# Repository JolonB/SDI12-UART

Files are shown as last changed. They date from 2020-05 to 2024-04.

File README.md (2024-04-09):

# SDI12-UART

Microcontroller independent implementation of SDI-12 over UART.
May also work for any sort of single wire communications protocol (not tested).

- [What is this?](#what-is-this)
- [What is SDI-12?](#what-is-sdi-12)
- [SDI-12 Protocol](#sdi-12-protocol)
  - [Electrical Interface](#electrical-interface)
  - [Communication](#communication)
- [Implementation](#implementation)
- [Glossary](#glossary)
- [References](#references)

---

## What is this?

After working on a project involving the use of SDI-12 sensors, I realised there was no SDI-12 library that was suitable for *any* microcontroller (well, any microcontroller that supports UART).
I was aware of the [Arduino-SDI-12](https://github.com/EnviroDIY/Arduino-SDI-12) library which was implemented entirely in software, but that uses the Arduino core library so would not work on *any* microcontroller.
(If you're working with Arduino, the Arduino-SDI-12 library may be the best if you're ok with the restrictions of the SoftwareSerial library).

The goal of this repository is to show a simple way to implement SDI-12 on *any* device with a UART driver.
"How?", you might ask.
Easy!
With hardware.

If you already know about SDI-12, feel free to skip to [Implementation](#implementation).

## What is SDI-12?

The SDI-12 (serial digial interface at 1200 baud) protocol was first released in 1988 designed by the US Geological Surbey's Hydrologic Instrumentation Facility and some private companies.
The SDI-12 specification is maintained by the SDI-12 Support group [1].

SDI-12 is a protocol often used for environmental monitoring due to it's low power operation.
It is intended for use in systems that are battery powered, low cost, and require a multiple sensors attached to one cable.
The SDI-12 protocol supports at least 10 sensors each with a cable length of 60 metres (200 feet).
One key reason for using SDI-12 sensors is that *all* SDI-12 sensors follow the protocol in the exact same way (barring slight differences between versions), so a variety of sensors can be used with little to no changes to the system [2].

## SDI-12 Protocol

*All information from [2]*.

### Electrical Interface

The SDI-12 protocol uses 2-3 wires to power and communicate with the sensor.
The figure below shows the bus connections.

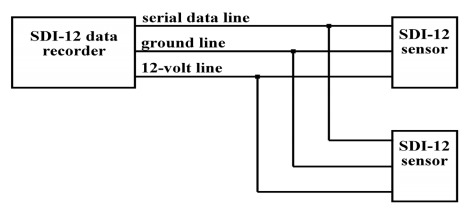
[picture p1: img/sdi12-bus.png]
SDI-12 bus


It is possible to not connect the 12 V line on some sensors, however, that is outside the scope of this repository.

The serial data line is a bidirectional (half-duplex) data transfer line.
It uses inverted logic as shown in the table below.

| Condition | Binary State | Voltage Range |
| --- | --- | --- |
| marking | 1 | -0.5-1.0 V |
| spacing | 0 | 3.5-5.5 V |
| transition | undefined | 1.0-3.5 V |

The 12 V line must be supplied with between 9.6 V and 16 V.

### Communication

#### Data

The SDI-12 protocol specifies that data recorders and sensors communicate via the exchange of printable ASCII characters over the data line.
"Printable ASCII characters" range from \<space\> (hex: 20) to ~ (hex: 7E).
There are three exceptions to this rule:

- responses from a sensor end with a carriage return and linefeed (`\r\n` or \<CR\>\<LF\>)
- CRC codes may include some non-printable ASCII characters
- packets returned by the High Volume Binary command

None of these use the most significant bit, which means that each "byte" of data needs to only be represented by 7 bits.
The full format for an SDI-12 byte frame is:

- 1 start bit
- 7 data bits, LSB first
- 1 even parity bit
- 1 stop bit

The first byte of any message should be the sensor address.
This is `0` by default but can be changed to any number from `0`-`9`.
Some sensors may support additional addresses from `A`-`Z` and `a`-`z`.

Rather than explaining all the commands, I will just point you to page 8 (Table 5) of [[2]](http://www.sdi-12.org/current_specification/SDI-12_version-1_4-Jan-10-2019.pdf).
Note that all commands begin with the sensor address (or `?` for wildcard) and end with `!`.
Certain manufacturers may have additional commands, but the main command set should be unchanged.

#### Timing

The image below shows a timing diagram for the SDI-12 protocol.
The tolerance for all timing is &pm;0.40 ms.
The only exception is the time between the stop bit of one character and the start bit of the next which should not be more than 1.66 ms.

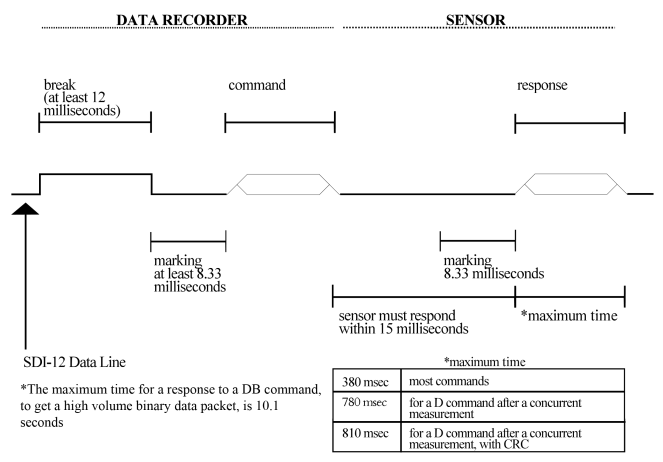
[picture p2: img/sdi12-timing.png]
SDI-12 timing


It should be noted that this diagram shows the **voltage levels** and not the **binary states**.
As in, a break is a period of spacing, which is a high voltage, but a low binary state.

The full communication protocol (for the data recorder) is explained below:

- data recorder sends a break by setting the data line to spacing (5 V) for at least 12 ms.
The sensor will never recognise a break less than 6.5 ms and will always recognise one greater than 12 ms.
- data recorder sends marking (0 V) for 8.33 ms.
This cannot be any longer than 100 ms otherwise sensors will go to sleep.
- data recorder sends the command to the sensor.
- data recorder gives up control of the data line within 7.5 ms of the end of the last stop bit and waits to receive data.

This must be repeated for every command if the sensors have fallen asleep again.
This occurs if a different sensor is addressed or if 87 ms of marking was detected by the sensor.

#### Retries (not yet implemented)

A data recorder must support retries.
A retry is needed if there was:

- no response from the sensor at least 16.67 ms after the last stop bit of the command.
- 8.33 ms of marking on the data line, after receiving the start bit of the response
- an invalid response

The first retry can be issued between 16.67 ms and 87 ms from the end of the last stop bit of the command.
If no valid response is received after retrying at least two times (with one retry more than 100 ms after the end of the break), the entire sequence of break and retries should be repeated two more times.

## Implementation

The implementation of SDI-12 was based heavily on the work done in [3].
The work I did can be found [here](https://jolonb.github.io/assets/pdf/final_report.pdf) if you're interested.
The goal is to make this information a bit more widely available and to provide alternate approaches for different microcontrollers.

There are so many types of microcontrollers so it's impossible to provide one solution for all of them.
This repository will showcase a few different ways to make it work.
Feel free to submit a pull request if you can add another design or make any changes to something.  
In any case, the base design will work for any microcontroller as the hardware works with standard UART.
Different designs can be created for specific use cases.

The most basic implementation is shown below.

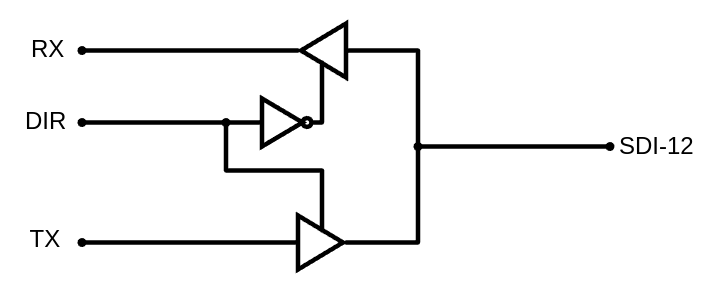
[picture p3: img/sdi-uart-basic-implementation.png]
Simplest SDI-UART implementation


This consists of two tri-state buffers and one inverter.
There may also need to be a high-value pull-down resistor (100–300kΩ) on the SDI-12 line, however, I'm not sure if that is built in to the sensor (if someone knows, let me know!)  
_However_, this implementation is unlikely to work in most situations for three reasons:

- It does not invert the logic. This only works if the microcontroller UART hardware supports inverted logic, or if the tri-state buffers are actually tri-state inverters (see [logic inversion](#logic-inversion)).
- It is assumed that this circuit operates at 5V because the SDI-12 specification requires 5V logic. If you are using a 3.3V microcontroller, you will need logic level shifters (see [logic levels](#logic-levels)).
- The TX line must be capable of sending a 12ms break signal. This can be done with hardware or sometimes in software (see [12-ms break](#12-ms-break)).

There are two modes of operation: transmit and receive.
The specifics of how it works will depend on the hardware you purchase; this information explains the operation of the circuit in the image above.  
When the DIR pin is set HIGH, the transmitter buffer is activated.
The signal on the Tx line will be propogated through to the SDI-12 line.
It will also go to the receive buffer, however, the inverter disables the receive buffer so nothing is read.
Technically, the RX tri-state buffer and inverter is optional if you choose to ignore any data received while transmitting, much like in [this circuit](https://archive.is/j75iI).
If the RX tri-state buffer _is_ included, it can then be enabled by setting the DIR pin LOW and allowing data received from the SDI-12 sensor to be received.

<!-- At the moment, there are 4 properties of the microcontroller you need to be aware of: inverted, reinitialisable, default voltage, and high voltage level.
Refer to the [glossary](#glossary) for definitions of these terms.

| Configuration | | Inverted | Reinitialisable | Default Voltage | High Voltage [V] |
| --- | --- | --- | --- | --- | --- |
| [1](hardware/config_1) | | No | No | LOW | 3.3 | -->

### Logic Inversion

TODO
<!-- TODO -->

### Logic Levels

TODO
<!-- TODO - maybe mention work in hardware/README.md -->

### 12-ms Break

If your microcontroller doesn't support sending a break signal of at least 12 ms, you will need to implement it another way.
There are two ways this can be done: with hardware, or with software.

The software approach is cheaper, but is not supported by all microcontrollers.
To do this, you need to close the serial device, set the output on the Tx line for 12 ms, and re-enable the serial device.
The following Arduino code shows how this could be done:

```c++
void sendSDI12Break() {
  Serial.flush();  // make sure everything has been sent
  Serial.end();  // disable serial
  pinMode(txPin, OUTPUT);  // set Tx pin to output
  digitalWrite(txPin, HIGH);  // or LOW if inverting signal with hardware
  delay(12);  // break for minimum of 12ms
  Serial.begin(1200, 7E1);  // re-enable serial
}
```

Remember, this isn't guaranteed to work on all microcontrollers.
I suggest testing this code (or similar code) before selecting the hardware.

The hardware approach is guaranteed to work for all devices, provided they have one free GPIO pin.
This involves connecting the Tx signal to the new GPIO through either an AND or OR gate (depending on whether you've inverted the logic in the microcontroller or on the PCB).
You can see this implemented below.
In this circuit, it is assumed that the microcontroller is inverting the logic, so an OR gate is used.
This allows the break signal to be sent by setting the FOut ("**F**orce **Out**") pin HIGH for 12 ms.

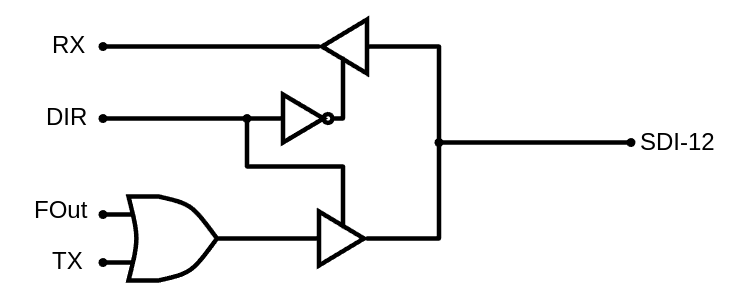
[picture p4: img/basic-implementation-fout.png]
SDI-UART implementation


While the FOut pin is LOW (default state), the output will be the same as the Tx pin.
The truth table for this is shown below.

| FOut | Tx | OUT |
| --- | --- | --- |
| 0 | 0 | 0 |
| 0 | 1 | 1 |
| 1 | X | 1 |

If you were inverting the logic in hardware, such as with tri-state buffers, you might consider using an AND gate instead and set the FOut pin LOW.
The truth table would change in this situation.

## Glossary

| Term | Meaning |
| --- | --- |
| CRC | Cyclic redundancy check, a form of error checking. |
| data recorder | The microcontroller being used to communicate with the sensor. |
| default voltage | The voltage (HIGH or LOW) on the Tx pin when not transmitting. This is almost always going to be HIGH, but it may vary for some microcontrollers. Only important if UART is not reinitialisable. |
| high voltage level | The voltage (in volts) of a HIGH signal. |
| inverted | In this context, refers to the UART driver outputting an inverted signal. This is likely the only case where default voltage is LOW. |
| reinitialisable | The ability for the UART to be initialised again after being deinitialised. |

## References

[1] Wikipedia Contributers, "SDI-12," Wikipedia, The Free Encyclopedia., 6 June 2017. [Online]. Available: [https://en.wikipedia.org/w/index.php?title=SDI-12&oldid=784017978](https://en.wikipedia.org/w/index.php?title=SDI-12&oldid=784017978). [Accessed 25 May 2020].  
[2] SDI-12 Support Group, "SDI-12 Specification," 10 January 2019. [Online]. Available: [http://www.sdi-12.org/specification.php](http://www.sdi-12.org/specification.php). [Accessed 2020 May 25].  
[3] A. Saari, S. A. Hinzey, J. R. Frigo, M. C. Proicou and L. Borges, "Using SDI-12 with ST microelectronics MCU's", Los Alamos National Lab, Los Alamos, 2015.

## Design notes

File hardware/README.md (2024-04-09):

# Hardware

The purpose of this document is to provide information about the different components used in the systems.
By breaking them down, it means the sections are modularised and can be built up to create the same functionality as required for any microcontroller.

Some sections may be a little bit theory heavy.
Working is shown in case there are mistakes so people can correct them and to provide a bit more information for those interested.
The equations provide help for minimising current in power critical situations (such as battery power, which SDI-12 sensors may be connected to).
However, if you want to skip straight to the implementation, just look at the schematic image.

## Level shifter

The most energy efficient level shifter designs I could come up with is shown below.
This assumes it is being fed into a high impedance input, such as a microcontroller or the gate of another MOSFET.
The level shifters are unidirectional as there is no need for them to be bidirectional.
The 1 M&Omega; resistors represent the load, which should be high impedance.
The 100 k&Omega; resistors can be increased to reduce the current, but increasing them too far will cause it to output the wrong voltage.

There are some instructions below for selecting the resistor for the 3.3->5 Inverted level shifter, but this information may also apply to all the other designs.
This does require extra information about the device the output is going in to, so may not be useful in most instances.

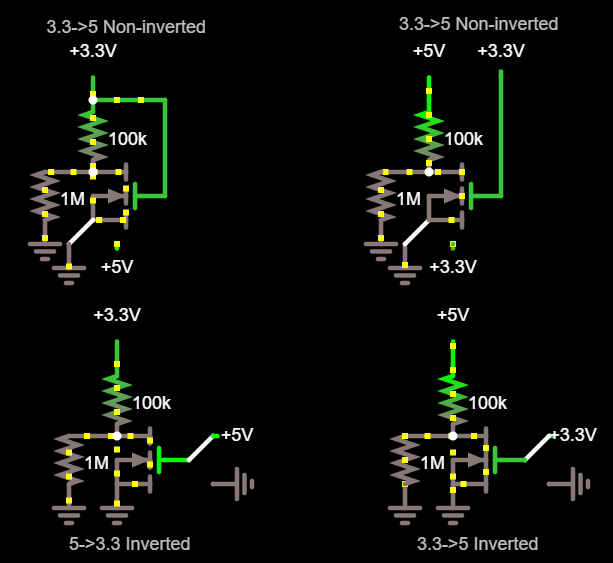
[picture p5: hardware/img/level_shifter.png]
Level shifters
  
[Link to simulation](https://www.falstad.com/circuit/circuitjs.html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)

The image below shows the output of the level shifter being fed into the input of a CMOS inverter.

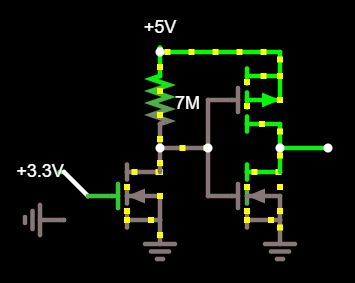
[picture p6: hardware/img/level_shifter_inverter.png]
Level shifter
  
[Link to simulation](https://www.falstad.com/circuit/circuitjs.html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)

---

If you want to work out the value of the resistor, follow these "steps" (or just skip to the end for the final equations).

When $V_{gs} = 3.3 \text{V}$, the lower left nMOS will be in the linear/non-saturation/ohmic/triode region, so the current through it is given by the equation:

$I_{ds} = \beta((V_{gs}-V_{t})V_{ds} - \frac{V_{ds}^2}{2})$

We will look at the left half of the circuit first.
We know that the current through the resistor is $I_{R} = \frac{V_{dd} - V_{ds}}{R}$ and that $I_{R} = I_{ds}$ at all times.

If we equate these and rearrange, we get:

$V_{ds}^2 - 2(\frac{1}{R\beta}+ 2V_{gs}-V_{t})V_{ds}+ 2\frac{V_{dd}}{R\beta} = 0$

We now know the input into the CMOS inverter is equal to $V_{ds}$.
Assuming the resistance is large (>1k), we know that the actual value of $V_{ds}$ is the lower solution to the quadratic.
Interestingly, the upper solution is <5V, so is technically valid but would not be the correct solution.
Therefore, we have:

$V_{ds} = \frac{1}{R\beta} + V_{gs} - V_{t} - \sqrt{(\frac{1}{R\beta} + V_{gs} - V_{t})^2 - 2\frac{V_{dd}}{R\beta}}$

Therefore, the current through the left branch is:

$I_{ds} = \frac{V_{dd} - V_{ds}}{R} = \frac{V_{dd} - \left(\frac{1}{R\beta} + V_{gs} - V_{t} - \sqrt{(\frac{1}{R\beta} + V_{gs} - V_{t})^2 - 2\frac{V_{dd}}{R\beta}}\right)}{R}$

when $V_{gs} = 3.3 \text{V}$

The calculation for when $V_{gs} = 0 \text{V}$ is a bit different in that it sets an upper bound for the resistance provided by the resistor.
You need to know the value of $I_{dss}$ for the transistor.
To simplify the explanation, this is the maximum current while the transistor is off and the value can be found on the datasheet.
Knowing this, we need to set the resistance such that $I_{R} > I_{dss}$.
Remember, $I_{dss}$ is the max current, so the current through the resistor will be limited to this value if a low enough resistance is selected.
We can write this as $\frac{V_{dd}-V_{ds}}{R} > I_{dss} \Rightarrow R < \frac{V_{dd}-V_{ds}}{I_{dss}}$.
Assuming this condition is satisfied, then $V_{ds} = V_{dd} - I_{dss}R$

In short, the current through the left branch is $I_{ds} = \frac{V_{dd} - V_{ds}}{R} = \frac{V_{dd} - \left(\frac{1}{R\beta} + V_{gs} - V_{t} - \sqrt{(\frac{1}{R\beta} + V_{gs} - V_{t})^2 - 2\frac{V_{dd}}{R\beta}}\right)}{R}$ when $V_{gs} = 3.3 \text{V}$ and $I_{ds} = I_{dss}$ when $V_{gs} = 0 \text{V}$.
$V_{ds}$ can be written as $V_{ds} = \frac{1}{R\beta} + V_{gs} - V_{t} - \sqrt{(\frac{1}{R\beta} + V_{gs} - V_{t})^2 - 2\frac{V_{dd}}{R\beta}}$ and $V_{ds} = V_{dd} - I_{dss}R$, respectively.

The next step is to feed the output of the circuit into the right branch.
This will allow you to find the optimal values to minimise the current from the source because if the output voltage is too low, the pMOS transistor will switch to the linear/saturation region. A pMOS transistor is in the off state when $V_{gs_p} > V_{t_p}$.
We know that $V_{gs_p} = V_{ds_{n1}} - V_{dd}$ and $V_{t_p}$ can be found on the datasheet.
Therefore, we have a requirement that $V_{ds_{n1}} - V_{dd} > V_{t_p}$.
The overall current of the circuit appears to be the lowest when the pMOS is on the edge of the cutoff region (it's probably best to give it a bit of breathing room though).

There's still a bit more work to do.
To get a rough idea of a resistance to use, look at [this graph](https://www.desmos.com/calculator/3hmn6u5ff4).
The resistance is on the x-axis and should not be greater than the point at which the red and purple lines intersect.
Past the intersection point, the pMOS is in linear/saturation.
The blue line represents the current (though multiplied by 100,000) through the left nMOS.
We can assume that if the pMOS is in the cutoff region that the right branch has minimal current ($I = I_{dss_p}$) therefore you only need to minimise the blue current curve.
As mentioned before, give a bit of breathing room. The default configuration in the graph would be best at 6 M&Omega;.
Make sure you play around with the values in Desmos to get the optimal value for your MOSFETs.

## Inverter

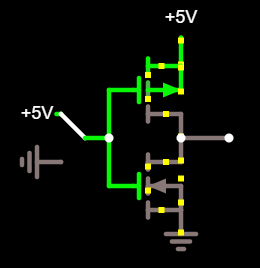
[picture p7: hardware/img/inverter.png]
Inverter
  
[Link to simulation](https://www.falstad.com/circuit/circuitjs.html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)

This is a basic CMOS inverter.
This does not have a level shifting stage because the input is already 5 V.

## Tristate Buffer

### Suggested chips

| Part number | Package |
| --- | --- |
| [SN74LV125A](http://www.ti.com/lit/ds/symlink/sn74lv125a.pdf) | TVSOP, SOIC, SOP, SSOP, TSSOP, DIP |
| [SN74LVC2G125](http://www.ti.com/lit/ds/symlink/sn74lvc2g240.pdf) | SM8, VSSOP, DSBGA |
| [SN74LVC2G241](http://www.ti.com/lit/ds/symlink/sn74lvc2g241.pdf) | SM8, VSSOP, DSBGA |

There are some differences between these buffers.
All examples will use **SN74LV125A**, so be aware of any changes you may need to make.
The other chips may be better if you don't need a DIP package as they only have two buffers rather than four.

## Basic Circuit

The following image shows a basic circuit which would work for configuration 1.
This section aims to explain how to modify this circuit to work for any other configuration.

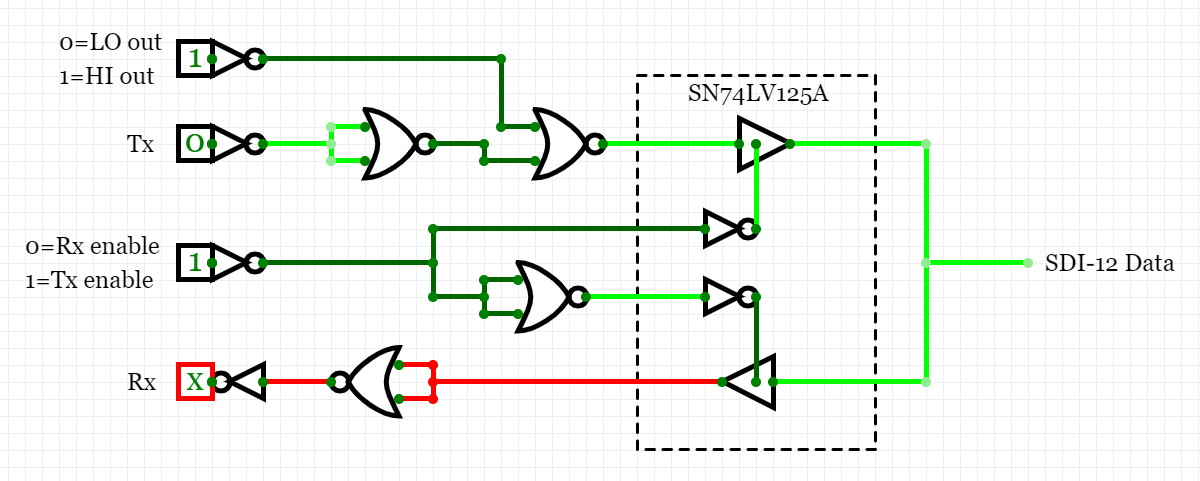
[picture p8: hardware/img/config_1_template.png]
configuration
  
[Link to "simulation"](https://circuitverse.org/users/21100/projects/95794)

Notes:

- the inverters at the inputs represent the level shifting inverters.
  - these are all inverting because inverting level shifters have a lower current draw.
- only one NOR gate is used for its intended function, the rest are used as inverters
- if the default Tx voltage is 0, place the NOR inverter *before* the NOR gate (as shown); if the default Tx voltage is 1, place the NOR inverter *after* the NOR gate.
- the inverter does not need to be on the Rx buffer enable pin (as shown), it could be connected to the Tx which would invert the control.

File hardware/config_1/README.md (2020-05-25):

# Config 1

This directory contains schematics for a device with the following properties:

- Inverted: No  
- Reinitialisable: Yes  
- Default Voltage: N/A  
- High Voltage: 3.3

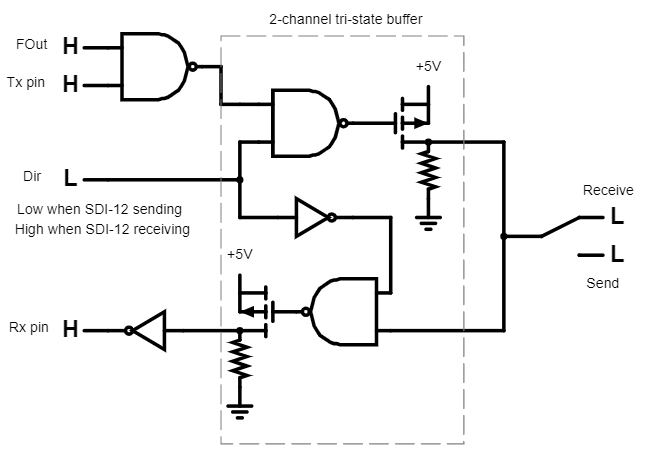
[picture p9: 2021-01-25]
img/sdi-uart-implementation.png

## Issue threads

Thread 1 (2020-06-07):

Please update the link check action to v1 or v1.0.3

gaurav-nelson, 2020-06-07:
https://github.com/JolonB/SDI12-UART/blob/master/.github/workflows/md-lint.yml#L33

Latest version fixes few issues with v1.0.2. I'd recommend switching to v1 tag or v1.0.3
PS https://github.com/gaurav-nelson/github-action-markdown-link-check/releases

Closed 2024-04-09.

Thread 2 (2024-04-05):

KiCad schematics

binomaiheu, 2024-04-05:
Dear Jolon,

Many thanks for this repository and for your elaborate bachelor thesis on developing an SDI-12 enabled IoT system. I'm currently on a similar quest actually ;). I am aware of the Arduino SDI12 library, which I'm currently testing, but I'm a little worried that it will interfere with the interrupts I'm using in my logger firmware, so i wanted to explore the hardware option for interfacing the UART with the SDI-12 bus as well. I did find the schematic on https://www.daycounter.com/Circuits/SDI-12/SDI-12-Interface.phtml which is also mentioned in your thesis, so i ordered some parts to test that, but I really like the way you are using the SN74LVC2G241 dual buffer to switch between TX & RX and wasn't aware of the need for the additional NAND gate on the TX line.

My electronics/KiCad skills are not the best, so I was wondering whether you would consider sharing the KiCad files for your SDI-12 interface ? I noticed the files under `hardware/config_1` are fairly empty if I'm not mistaken. In any case a big thanks for your work !

Regards,
Bino (from Belgium)

JolonB, 2024-04-06:
Hi Bino,

Thanks for getting in touch. It's great to hear that you had a look at my thesis and are interested in working with SDI-12. I'm more than happy to help!

I did probably get a bit ambitious with this repository and ended up **not** actually doing much work outside of the README, meaning `config_1` (and all the other non-existent configurations) are pretty empty... whoops :/ This will just have to be motivation to update this repo.

---

Anyway, you mentioned the additional NAND gate on the Tx line. Are you referring to the one I've circled here?

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

This was added to implement the _break_ condition (12ms high voltage (logic 0)) in the SDI-12 specification. Some UART buses might be able to do this, however, we were working with an ESP32 running MicroPython, which seemed to prevent us from doing this. This NAND gate exists as a workaround for the inability to implement a _break_. The **FOut** pin allows us to send the _break_ by setting that pin for 12ms instead.

If you are using a microcontroller that can send a 12ms break on the Tx pin, you won't need to include this NAND gate; you'll be able to simplify it down to use just 3 pins (Tx, Rx, and direction).
If you don't know if your microcontroller's UART bus can send a 12ms break, it may even be possible to manually set the output register for the Tx pin to 5V for 12ms.

I believe the design at https://www.daycounter.com/Circuits/SDI-12/SDI-12-Interface.phtml should work. The only issue is that all of your Tx data will also be received by Rx, so you need to filter that out. That's why I used the dual buffer

---

I'll try to update some schematics tomorrow and I'll let you know when I've done it. If you want to, you could let me know what microcontroller you are using and I can give you some advice on how I would design the SDI-12 circuit or—if I have the time—I could upload a new design to this repo that will work for your microcontroller :)
The designs I show in my thesis and on this repo have been specifically made for ESP32 devices. I want to make designs for other devices, but haven't had the motivation to do so (until now!)

JolonB, 2024-04-07:
Hey @binomaiheu

Since you mentioned Arduino, I've made a design that should work for an Arduino with **5V** GPIO.

This design uses two components:

* 74LVC1G04: 1-channel logic inverter. Needed to make the Rx and Tx lines operate exclusively of eachother.
* 74LVC2G240: Inverting tri-state buffer.

There is also a large pull-down resistor. I'm not sure if it is needed. I never used one there; maybe some sensors have one built in?? I'll leave that up to you to test because I no longer have any SDI-12 sensors.

[output.pdf](https://github.com/JolonB/SDI12-UART/files/14895603/output.pdf)

As you can see, this design does not need the NAND gate with the `FOut` input. As I mentioned in my previous comment, this is only needed if your UART bus cannot send the break signal. There are two ways this can be achieved: hardware support for break signals, or the ability to close and reopen a UART bus. It seems that Arduinos support the latter.

I'm basing the following code on [this code from the RS485 library](https://github.com/arduino-libraries/ArduinoRS485/blob/1993679d2b0588d650bf064b1d62c2ca67b88a0e/src/RS485.cpp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). You should be able to implement a break like so:

```c++
void sendSDI12Break() {
  Serial.flush();
  Serial.end();
  pinMode(txPin, OUTPUT);
  digitalWrite(txPin, LOW);  // remember, this will be inverted
  delay(12);  // minimum 12, could do slightly longer
  Serial.begin(1200, 7E1);  // 1200 baud; 1 start, 7 data, 1 even parity, and 1 stop bits
}
```

You'd also need to manage switching the direction yourself. I believe my code spent most of the time in the receive state and only switched to the transmit state when it was needed. (This is why I think the pull-down resistor (R1) could be needed. It just means Rx has a defined input)

binomaiheu, 2024-04-07:
Hi @JolonB !

Thanks a lot for taking the time for such an the elaborate response! We had the first proper spring weekend here in Belgium so haven't had the change to test much further, but as usual nice weather doesn't last very long here, so I'll get back to it tomorrow :). Normally the components i ordered to try the schematic on that daycounter website should arrive then as well.

I'm currently using both the Atmel1284p (as found on the Sodaq Mbili boards) and the SAMD21G (as on the Arduino MKR boards). Both using 3.3V level logic, so the original schematics should be ok. The final logger will be using a SAMD.

Good tip about the UART being able to send the break signal itself, I wouldn't know by heart, but I'll try that tomorrow, that would indeed save one GPIO line, thanks ! And thanks for uploading the schematic, great to get me going (have only done small things in kicad, but pretty sure i'll get the hang of it).

I'll keep you updated on my progress !

Cheers,
bino

JolonB, 2024-04-08:
Hey @binomaiheu

There is something to be aware of when using the original designs with a 3.3V microcontroller. When I did the environmental monitoring project, I used NAND gates with **TTL** logic levels, which meant that 3.3V signals would be detected as a HIGH signal.

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

If you use a CMOS chip instead of TTL, the 3.3V signals will be undefined, so you have to be careful not to do that.

_However_, instead of using a TTL logic gate, I recommend using the new circuit I made but with a logic level shifter connected to the microcontroller to convert the 3.3V signal to 5V and vice versa. With the logic level shifter, it doesn't matter if you use a TTL or CMOS chip—they'll both work.

Keep me updated. I'm keen to hear how it goes.

Jolon

binomaiheu, 2024-04-10:
Hi Jolon,

I did some more testing with sending a break via the UART line. On the Arduino MKR (SAMD21 MCU), it didn't seem to work with the standard UART pins for Serial1 (13 & 14). For some reason the bus stopped working and the entire device froze after a few iterations (i setup a small firmware to print a character every 2 seconds, alternately preceeded by the 12 ms break and not. So I dug a little deeper and created an own hardware UART following https://docs.arduino.cc/tutorials/communication/SamdSercom/. That seemed to work, also defining the correct number of bits (7) and parity etc..

Source is below :
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
binomaiheu, 2024-04-11:
Few minor updates:

- I have added a jumper for which one end is connected to the 3.3V (logic HIGH at the input side of the NAND gate, so will always return the inverted output of TX), effectively bypassing the Fout to be able to play around with it.

- Also, after some searching, I believe the following chip (https://www.ti.com/product/SN74AHCT1G00) could also be used for the NAND gate,that seems to be compatible with TTL logic (input > 2V for logic high, irrespective of Vcc), correct ?  I could only find quad-input SN74LS00, and that seemd a bit overkill for our purposes :).

Cheers,
b.

JolonB, 2024-04-11:
Hi @binomaiheu

* That's a shame that disabling and re-enabling the UART bus didn't work. I had a similar issue when using ESP32, but I assume it must work on some hardware so it's always worth a try. It's good to see you found a software solution though. That little 52us pulse _could_ be an issue in some situations, but I don't think it will be for SDI-12. See the image below for my understanding. The letter `g` sent as a 7-bit message is transmitted as `1110011` (the actual binary representation is `1100111`, but it gets sent in reverse order). Before the payload, you have the start bit, and afterwards there is the stop bit (which is just 3.3V).
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
However, the thing to remember is that after sending the break for 12ms, the SDI-12 spec requires you to send "marking" for at least 8.33ms. Marking is 0V, which is the default state of the SDI-12 bus. This is the equivalent of 3.3V when uninverted, which is the default state of the UART bus (see where I'm going with this?). Basically, when the break finishes, re-enabling the UART bus forces it to transition from 0 to 3.3V. However, you want to send marking immediately afterwards, which is also 3.3V, so there is no 52us pulse. I hope I'm making sense here.
All you need to do is adjust your code to include a >8.33ms marking (e.g. `delay(10);`) after the break. Then it'll look like this. I've drawn an orange line to indicate where the 52us pulse would be. As you can see, it is only an issue because you tried to send data too soon after the break. The marking essentially extends the 52us pulse to 8.33ms so you shouldn't see the pulse at all on your oscilloscope anymore. (Remember, this image has the logic inverted so it is flipped compared to the one above)
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

* The schematic looks right to me. But it's still a good idea to check it again :)

* Yep! The SN74AHCT1G00 should work well. In fact, the datasheet even explicitly mentions that it can be used for it..
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
I did notice, however, that the chip is technically a CMOS chip and it mentions that there is higher current draw when using TTL levels, which might be a problem since the input from Tx will be 3.3V by default
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
It might be worth testing if that'll be an issue for you.
The 74LS00 also mentions that it'll work.
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
I suppose it is up to you which one you choose. If you choose to continue with the 74LS00, [apparently it's a good idea](https://electronics.stackexchange.com/questions/641411/why-should-you-not-leave-the-inputs-of-unused-gates-floating-with-74ls-series-lo) to connect the unused inputs to Vcc.

I won't say whether I think that sending the break with the UART pins or with the NAND gate is the better option, because I don't want to give you incorrect advice on something I haven't tested. The downsides of the UART solution is there could be issues that aren't obvious now (for example, the interrupt might affect something else). The downsides of the NAND gate is that there could be higher current draw, and there is the cost of an extra component.

---

> I was stupid enough to order them in packages which are completely beyond my soldering capabilities

I did the same thing when working on SDI-12 4 years ago. I think it happens to everyone at least once 😅️

binomaiheu, 2024-04-16:
Hi Jolon,

To keep you updated, I checked the schematics & PCB with a colleague who has more experience with electronics than I do and integrated the 12V/5V and 3.3V onto the PCB as well along with the stuff we discussed above. I believe indeed you are right concerning the 8.33 ms marking, so it should be possible to use the UART and leave out the "FOut" via the NAND gate. But I included both options for testing.

I just ordered the PCB ... with the correct footprints ! (I hope), so I'm looking forward to the result. Will get back here when I receive my toys & have tested them !

Cheers,
b.

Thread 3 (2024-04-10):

a multisim simulation for your design

wushuaixue, 2024-04-10:
Dear Jolon

How's everythong going? About serial days ago, I received a assignment to let me design a board to read SDI-12 data from a sensor and I found your outcome in github. Your excellent work help me know the SDI-12 protocal and it's timing very well. Thank you for your work!

In your last version, I note that you said because you can't find a simulation of tri-state buffer so you design a two channel tri-state buffer yourself. So I tried to make a simulation on computer using Multisim befor the chip I bought coming. If you are interested in the simulation, just to tell me. If you had done that befor, just ignore this issue and forgive my rude question.

Thank you again for your excellent work! I truely get a lot from your passage. Since my english is not fluent, sorry for your reading. Bless you have a good day!

wushuaixue
2024,4,10 from Beijing
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

JolonB, 2024-04-10:
Hi,

Thanks for getting in touch. I'm always glad to hear that this repository has helped people.

Your question is definitely not rude. As you've noticed, I've updated the repo to remove that there was no tri-state buffer in the simulation. Either I didn't notice it at the time,
 or the simulation tool may have been updated, but I have now found a tri-state buffer component.
For simple simulations and tests, I tend to use [this simulation tool](https://www.falstad.com/circuit/circuitjs.html), so I'm not too familiar with MultiSim. Since I haven't used SDI-12 recently, I personally probably won't have much use for the simulation. However, it looks like you've done a good job of this simulation, so if you're willing to share it publicly, feel free to create a pull request to merge it into this repository (or attach the file (or a .zip file) to a comment here) 😃

Thanks

Jolon

P.S. your English is very readable. Keep up the good work!

wushuaixue, 2024-04-11:
Dear Jolon

I am so glad to receive your replay. That's the first time I receive a lettter from github, just like your idol give you a letter(a little exaggeration). Today I received my chip delivery and maybe because of the line I used is too long. The outcome have hign frequent noise, but I will review some filtering things these things or try to use some short line.

Get back to the bussiness, I am not that familier with github so I dont know how to create a pull request. So I just send the  simulation here. You can try the Multisim application that really strong. And if you have any questions with the file, that's okay to ask me. I dont browse github everyday so you can also send a email to me. My email is X1417155586@163.com. Thanks again for all your work.

Thanks reply again. Take good care of yourself.

wushuaixue
2024.4.11 from Beijing
[SDI-12.zip](https://github.com/JolonB/SDI12-UART/files/14940512/SDI-12.zip)

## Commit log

2020-05-25 Begin config_1
    [config_1.kicad_pcb, config_1.sch]
2020-05-26 Write mosfet theory
